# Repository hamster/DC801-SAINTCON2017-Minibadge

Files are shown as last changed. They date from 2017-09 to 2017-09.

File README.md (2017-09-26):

# DC801-SAINTCON2017-Minibadge
Minibadge design for the 2017 SAINTCON badge with a DC801 theme

Powered
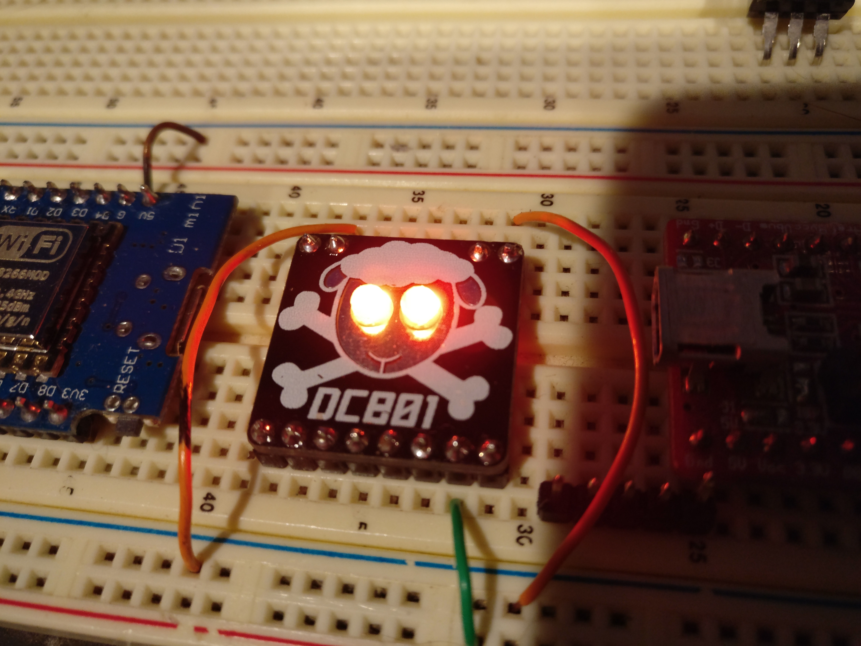
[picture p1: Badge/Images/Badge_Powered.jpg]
Powered


Front
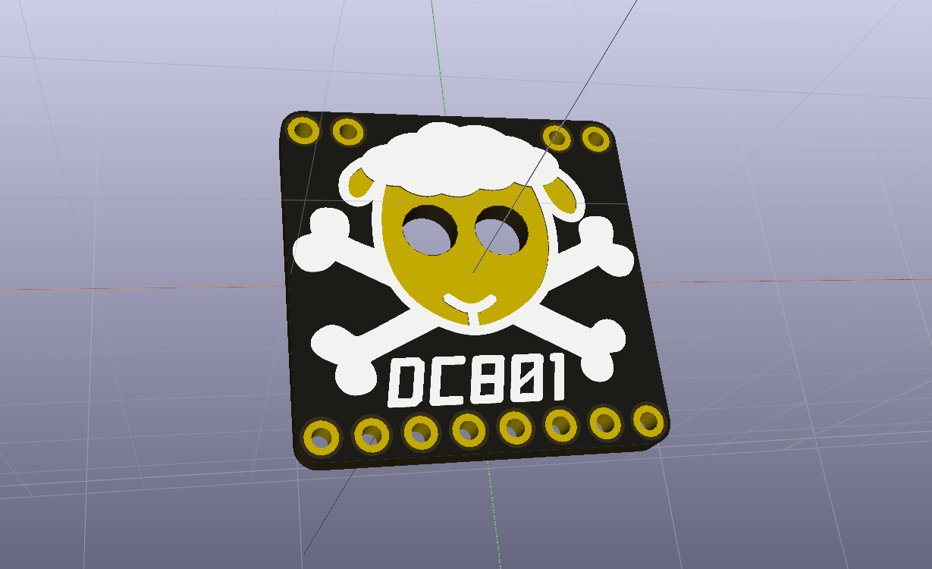
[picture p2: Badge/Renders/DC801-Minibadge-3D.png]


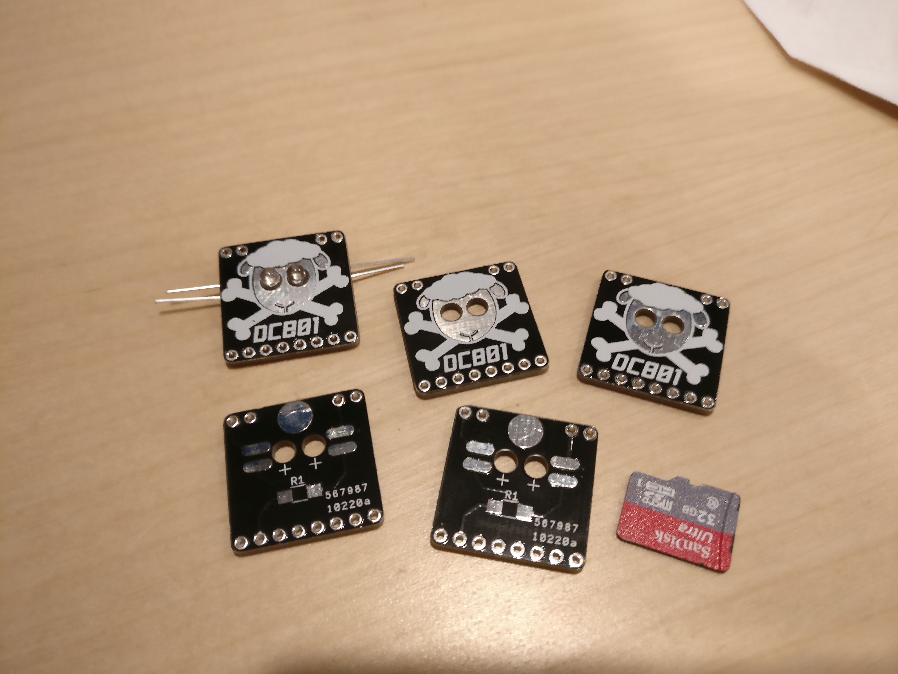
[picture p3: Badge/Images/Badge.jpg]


Back

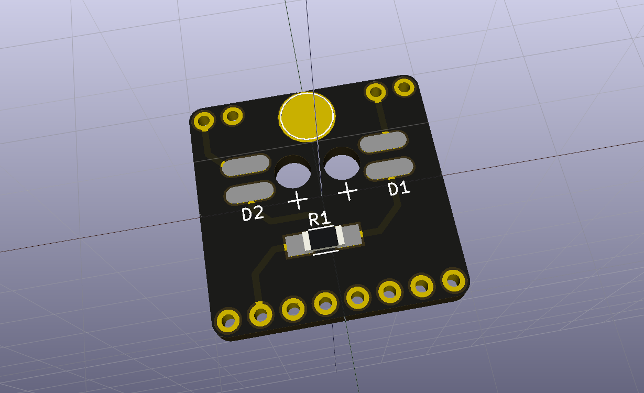
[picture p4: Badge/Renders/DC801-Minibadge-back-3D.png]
Back


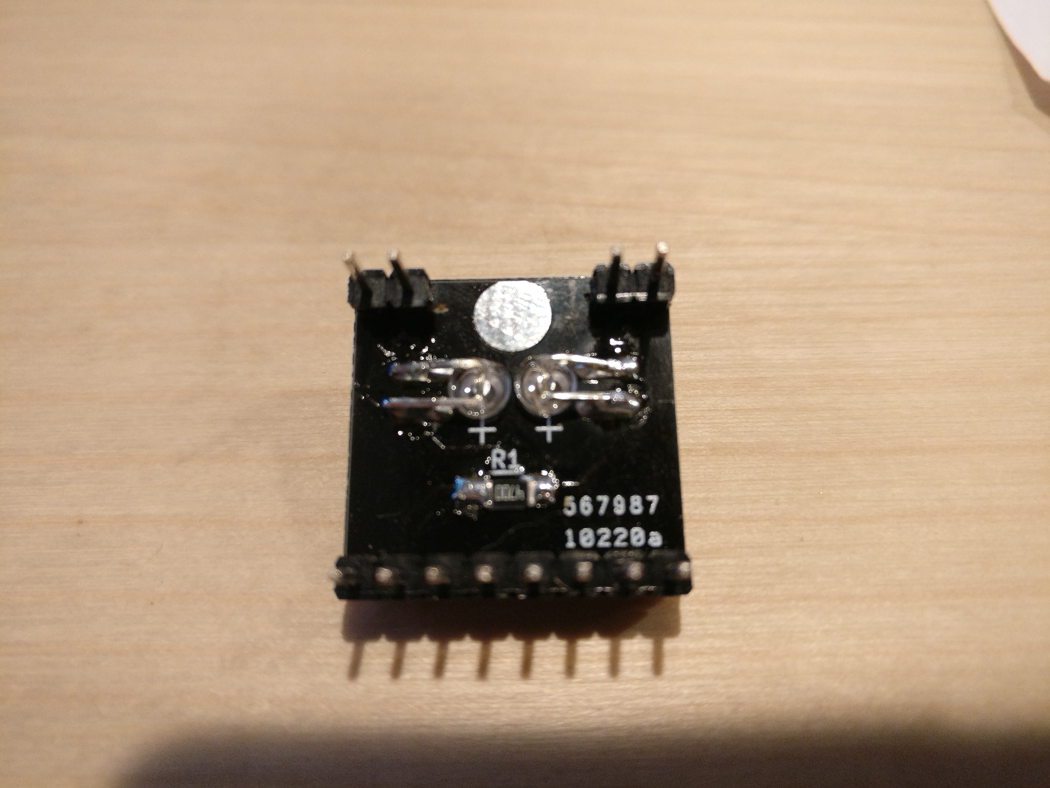
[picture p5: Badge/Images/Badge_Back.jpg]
Back


The Minibadge includes a spiffy DC801 design and two automatic slow-cycling RGB LEDs

The Minibadge can be used in two ways:

1. SAINTCON Minibadge Mode
2. Shirt Pin Mode

# Instructions for SAINTCON Minibadge Mode

1) Insert the LEDs into the back of the board with the shorter legs toward the top
2) Bend the legs of the LEDs over to contact the pads
3) Trim legs to pads and solder
4) Pick a resistor and solder R1:
   0 - Brightest, 20-55mA
   470 - Bright, 3-4mA
   1k - Not so bright, 1.5-2mA
5) Break the pin headers to fit 
6) Cut the sockets into two 8 pin sockets 
7) Insert the sockets with pins into your SAINTCON badge
8) Place the DC801 Minibadge onto the pins and solder
9) Flip your SAINTCON badge over and solder on the sockets

# Instructions for Shirt Pin Mode

1) Follow above, but don’t use the pin headers
2) Solder included button pin to large pad at top

# BOM

Prices/sourcing as of 10/2017
Part prices do not include shipping costs - typical was about another $0.30 per unit

Item | Part Number | Sourcing | Cost Each (100 unit pricing) | Needed per kit | Total
-----|-------------|----------|------------------------------|----------------|------
PCB | 100 qty, black silkscreen | [seeed](https://www.seeedstudio.com/fusion_pcb.html) | $0.334 | 1 | $0.334
D1,2 | Chanzon AA0018x100 3mm LED | [Amazon](https://www.amazon.com/gp/product/B01C19ENH8) | $0.075 | 2 | $0.15
R1 | Yageo RC1206JR-070RL 0 Ohm | [Mouser](http://www.mouser.com/Search/ProductDetail.aspx?R=RC1206JR-070RL) | $0.006 | 1 | $0.006
R1 | Yageo RC1206FR-07470RL 470 Ohm | [Mouser](http://www.mouser.com/Search/ProductDetail.aspx?R=RC1206FR-07470RL) | $0.009 | 1 | $0.009
R1 | Yageo RC1206FR-071KL 1k Ohm | [Mouser](http://www.mouser.com/Search/ProductDetail.aspx?R=RC1206FR-071KL) | $0.009 | 1 | $0.009
Pins/Sockets | Pins and Sockets, 40 pin | [Amazon](https://www.amazon.com/gp/product/B074HVBTZ4) | $0.26 | 1/2 | $0.13
Shirt pins | Mudder Butterfly Clutch Tie Tacks | [Amazon](https://www.amazon.com/gp/product/B06VXNN1HK) | $0.0699 | 1 | $0.0699
Bags | Metallic foil clear/black | [Amazon](https://www.amazon.com/gp/product/B01DMG9BQW) | $0.1849 | 1 | $0.1849
Cards | Instruction Cards (500 qty) | Vistaprint | $0.01998 | 1 | $0.01998
Total | Per each board kit | | | | $0.913

# Battery Holder

Included in the [Shirt Pin Battery](/Shirt%20Pin%20Battery) folder is a board that can hold a battery to power the badge and attach to your shirt, if you want blinkies in a tiny package.

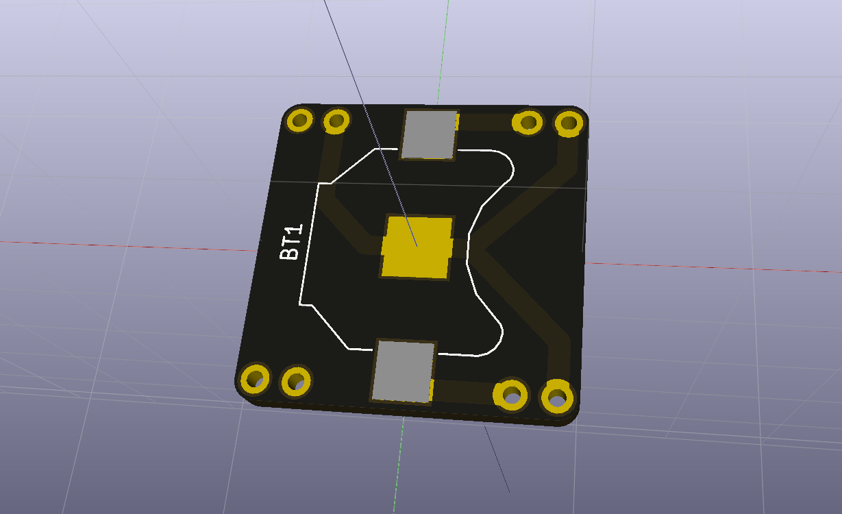
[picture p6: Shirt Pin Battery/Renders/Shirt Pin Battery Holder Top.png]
Shirt Pin Battery


Hope you enjoy!

@hamster

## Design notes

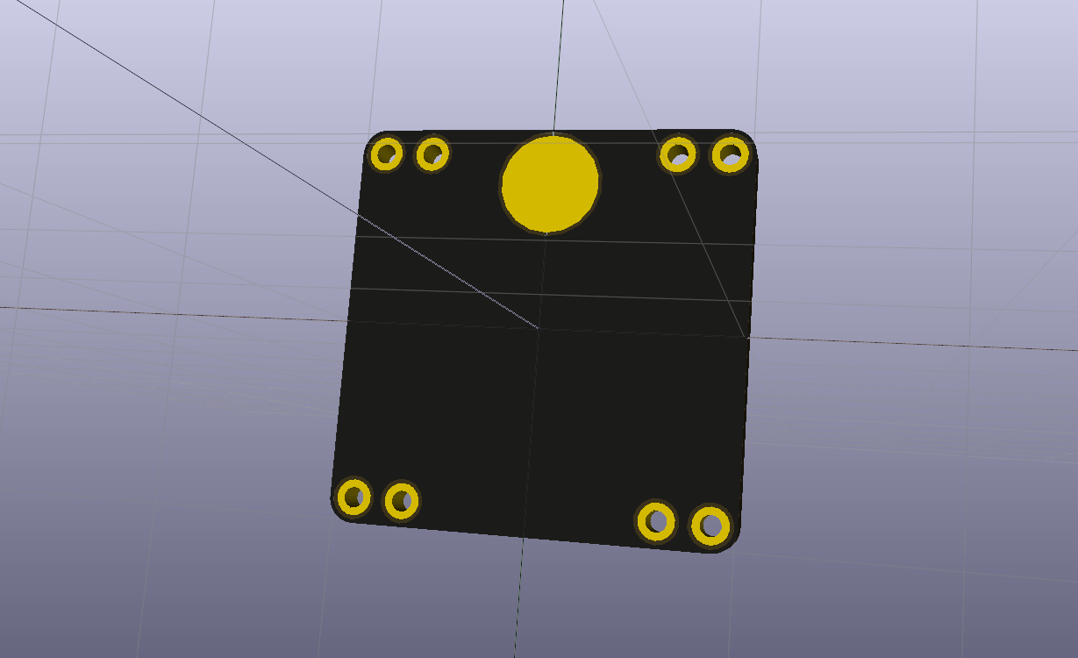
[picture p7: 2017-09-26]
Shirt Pin Battery/Renders/Shirt Pin Battery Holder Bottom.png

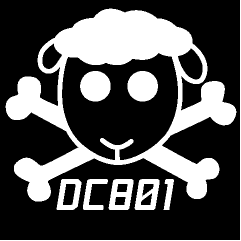
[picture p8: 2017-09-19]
Badge/Graphic Design/Sheep Head.bmp

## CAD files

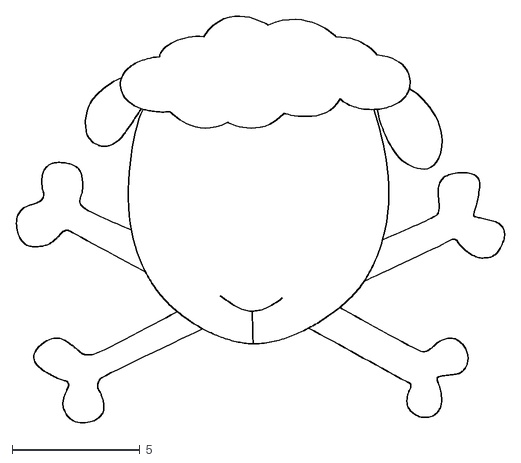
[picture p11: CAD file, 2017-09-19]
Badge/Sheep Head - Line Art - Sheep.dxf
19.1 x 15.9

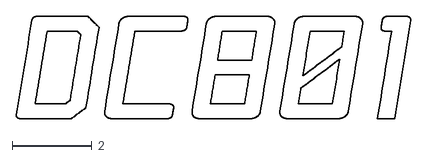
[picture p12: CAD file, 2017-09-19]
Badge/Sheep Head - Line Art - Text.dxf
9.90 x 2.56

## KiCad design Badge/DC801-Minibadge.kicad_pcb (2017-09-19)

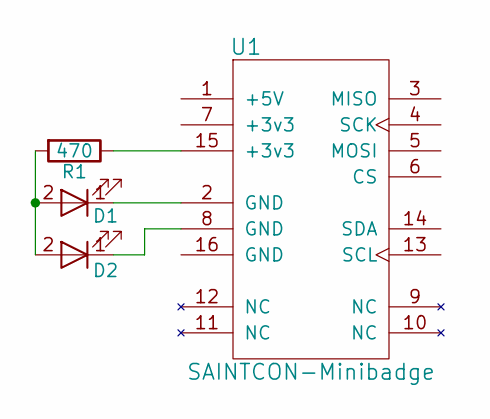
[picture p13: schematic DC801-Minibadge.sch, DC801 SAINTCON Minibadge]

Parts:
D1: LED; LED-3.0mm-ThroughBoard
D2: LED; LED-3.0mm-ThroughBoard-Flip
R1: 470; R_1206_HandSoldering
U1: SAINTCON-Minibadge; SAINTCON-Minibadge-NoSPI-NoSilk

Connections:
unnamed: D1.1 (K), U1.2 (GND)
unnamed: D1.2 (A), D2.2 (A), R1.2
unnamed: D2.1 (K), U1.8 (GND)
unnamed: R1.1, U1.15 (+3v3)

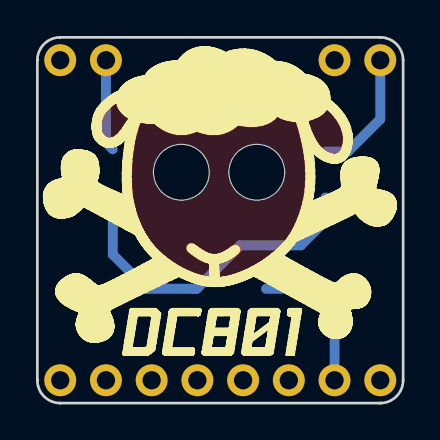
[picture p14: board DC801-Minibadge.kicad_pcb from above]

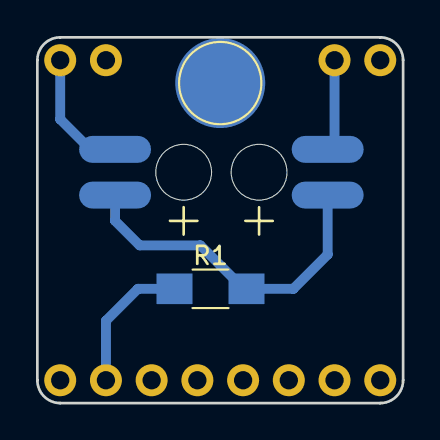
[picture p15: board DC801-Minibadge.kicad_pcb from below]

Board: 2 copper layers, 20.3 x 20.3 mm, 4 parts (3 on the bottom side), 4 nets.

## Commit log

2017-09-19 Adding design files
    [DC801-Minibadge-B.Cu.gbl, DC801-Minibadge-B.Mask.gbs, DC801-Minibadge-B.Paste.gbp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]
2017-09-24 Add BOM
2017-09-24 Fix links in BOM
2017-09-24 Add shipping estimate to BOM
2017-09-24 Update the qty needed per board to correct the per-board price in BOM
2017-09-24 Updating pin/socket calculation to account for lose when trimming
2017-09-25 Moved the badge to a subdir
    [DC801-Minibadge-B.Cu.gbl, DC801-Minibadge-B.Mask.gbs, DC801-Minibadge-B.Paste.gbp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]
2017-09-26 Adding battery holder Adding actual images
    [Shirt Pin Battery Holder-B.Cu.gbl, Shirt Pin Battery Holder-B.Mask.gbs, Shirt Pin Battery Holder-B.Paste.gbp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]
2017-09-26 Adding mentions of the shirt pin battery
